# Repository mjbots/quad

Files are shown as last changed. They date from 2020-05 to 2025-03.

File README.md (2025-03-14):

mjbots quad
===========

Source and design files for the mjbots quad series of robots, their
controlling interfaces, and utilities for developing and operating
them.

* GitHub https://github.com/mjbots/mjmech
* Most files are free hardware and software: Apache 2.0 License
* Overall F360 assembly: https://a360.co/4bPBs6g

Directory structure
-------------------

* **base/** - C++ source files common to many applications.
* **ffmpeg/** - C++ ffmpeg wrappers.
* **gl/** - C++ GL wrappers.
* **mech/** - C++ source files specific to walking robots.
* **simulator/** - C++ source files for a quadruped simulator.
* **utils/** - Utilities for development and data analysis.
* **configs/** - Configuration files for different robots and applications.
* **hw/** - Hardware design files along with firmware.
* **docs/** - Documentation.

First Time Setup
----------------

The following should work on Ubuntu 20.04 or 22.04.

```
./install-packages
```

For Ubuntu 24.04, you will also need to manually download and install an appropriate libtinfo5 package from 22.04.  https://packages.ubuntu.com/jammy/amd64/libtinfo5/download

Building for host
-----------------

```
tools/bazel test //...
```

Running simulation
------------------

```
./bazel-bin/simulator/simulator -c configs/quadruped.ini
```

Then point your web browser to `http://localhost:4778`

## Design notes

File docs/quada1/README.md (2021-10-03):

# Getting started with the quad A1 #

## Safety ##

The mjbots quad A1 is a high performance robot capable of very fast
and powerful motions.  It is not recommended for use in the vicinity
of untrained personnel and especially not children or others who do
not appreciate what it is capable of.

Minimize physical handling of the robot while the power switch is on,
as malfunctions may cause legs to to move rapidly, creating pinch
hazards.

## Turn on ##

1. Ensure the switch is in the "off" position.  When off, the LED side of the switch is *not* depressed.

2. Insert a 4Ah ONE+ battery.  It may be necessary to apply a moderate tap with your fist in order to get both retaining clips to latch.

3. Flip the quad A1 over to be right side up and extend legs to be maximally stretched out, flat against the ground.  This is the "turn-on" position.
  * NOTE: The software is able to detect *some but not all* invalid
    turn-on positions.

4. Activate the power switch.  This means pressing the side with the LED down.

5. After ~30s, the robot's wifi access point will become available.  Connect to it.

6. Using Chrome, the only currently supported browser, navigate to http://192.168.16.47:4778

## Joystick ##

The web control application supports a connected gamepad, which is the
simplest means of controlling the robot.  The "Y/4" button on the
gamepad enables mode select, while the d-pad up and down allow you to
cycle between modes.  Once you pick a mode that is not "Stop", the
quad A1 will stand up.

While moving, the left analog stick controls translation, while the
left and right motion of the right analog stick controls yaw.

When stopped, the left trigger can be pulled to enable "emote mode".
In that mode, the analog sticks control the attitude of the body.

## Keyboard ##

It is also possible to operate the robot with a mouse and keyboard.
The mouse can be used to click and select a mode.  WASDQE keys can be
used to pilot the quad A1 as per the on-screen display.

# Maintenance #

## Belt tension ##

The leg belts need to be kept appropriately tensioned to minimize the
possibility of belt skipping, while not overly stressing the 3d
printed upper leg structure.  The M3 adjustment bolt in each leg can
be used to adjust that tension.  As the belts stretch with age, it
will likely be necessary to use a longer bolt than the M3x12 initially
installed.  M3x14 is the longest suitable bolt.

## Rezeroing leg ##

If the leg is disassembled or re-assembled, or the belt skips, then that leg will need to be re-zeroed.  This can be accomplished as follows:

1. Lay the quad A1 upside down on a flat surface.
2. Install the leg zeroing fixtures on the leg in question.  The lower
   leg qdd100 rests on the curved part of the large fixture, and the
   upper part restrains the upper leg.
3. The smaller fixture registers the upper and lower leg together.
   Slide it down as far as possible, then attempt to get the lower leg
   as centered as possible in any remaining play.
4. Connect to the robot and stop the existing software:

```
ssh -i mjmech/utils/ssh/mjbots.ssh pi@192.168.16.47
sudo screen -r
<CTRL-c>
```

5. Determine the leg number of the leg to be rezeroed.  When looking
   from the top, the legs are numbered as follows.  The "front" side
   is the one with the power switch. (note the robot is upside down
   now, so this will be mirrored):

```
   1      2

     FRONT

     BACK

   3      4
```

6. Rezero the leg, using the leg number from above.

```
./zero_leg.py -l 1
```

This will report the current position of each three leg servos.  Press
<enter> when the leg is in position to zero that leg.

7. If more legs need to be rezeroed, the fixture can be moved between
   legs and the step 6 command run more as necessary.

8. Shutdown the computer, wait 15s, then turn off the power switch.

```
shutdown -h now
```

9. At this point the quad A1 can be set in the "turn-on" position and
   started up as normal.

## Change ssh key ##

The quad A1 is initially provisioned with an ssh key that is common to
all machines.  This is not normally a problem, as the SSID is unique
and the password is secret.  If you wish to expose the quad A1 to a
wider network, first contact info@mjbots.com to discuss your risk
profile.  Second, you may wish to change the default ssh access key.

First, use `ssh-copy-id` to install a new key on the quad A1:

```
ssh-copy-id -o "-i utils/ssh/default.ssh" pi@192.168.16.47
```

Then, ssh in, and remove the old key.

```
ssh pi@192.168.16.47
vi .ssh/authorized_keys  # remove the info@mjbots.com line
```

## Upgrading software ##

1. Compile:

```
tools/bazel build --config pi -c opt //mech:quad_deploy.tar
```

2. Copy it to the robot:

```
rsync -Pv -e "ssh -i utils/ssh/default.ssh"  \
  bazel-out/armeabihf-opt/bin/mech/quad_deploy.tar pi@192.168.16.47:
```

3. Perform the upgrade and restart the software.

NOTE: If any configurations have been modified, you will want to
manually capture those now, as this process will reset all
configuration to factory default.

```
ssh -i utils/ssh/default.ssh pi@192.168.16.47
sudo screen -r
<CTRL-c>
cd /home/pi
sudo -u pi tar xvf quad_deploy.tar
sync
cd mech
./start-robot.sh
<CTRL-a d>
```

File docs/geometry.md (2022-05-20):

# mjmech geometry #

## Unit naming conventions ##

Quantities expressed in a certain unit should have that unit included
as a suffix that variable name.

## Frame naming conventions ##

Quantities which are expressed relative to some frame or frames have those frames suffixed on the variable name using the simbody conventions :https://simtk.org/docman/view.php/47/231/SimbodyTheoryManual.pdf

As there, common frames may be abbreviated with a single uppercase
letter.

## Frame conventions ##

Coordinate systems are right handed, if there is a human associated
direction, they should be interpreted as:

* x is positive forward
* y is positive right
* z is positive down

## Common frames ##

Leg Frame (G): The leg frame is located at the center of the shoulder
joint, with +x facing forward, +y facing right, and +z facing down.
In this case, "forward" is oriented away from the center of the robot
in the longitudinal direction, and "right" is measured relative to
that.

Body Frame (B): This frame is oriented at the center of the quadruped
body and fixed to the chassis.

CoM Frame (M): This frame is fixed to the chassis at the center of
mass as measured with the legs in idle position.  It is oriented to be
level with the ground, so +Z is always down w.r.t. gravity.  The frame
has a yaw such that +X is pointed to same heading as Body +X.

Attitude Frame (A): This frame is fixed to the chassis center of mass.
+Z is down w.r.t. gravity.  The rotation of +X/+Y is arbitrary at
power up, and follows the rotation of the B/L transform.

Robot Frame (R): This frame is offset from the Body Frame (B) and
referenced in the same manner, but may be offset or rotated to apply
cosmetic kinematic changes.

Terrain Frame (T): This frame is located at the center of mass,
projected along the body Z direction at the ground location.  It is
oriented parallel to the local ground terrain and rotated to be
consistent with the A frame.

Local Frame (L): This frame is oriented such that down is parallel to
gravity.  Other degrees of freedom are initialized with the quadrupeds
body center at turn on, and have no absolute correlation with the
outside world.

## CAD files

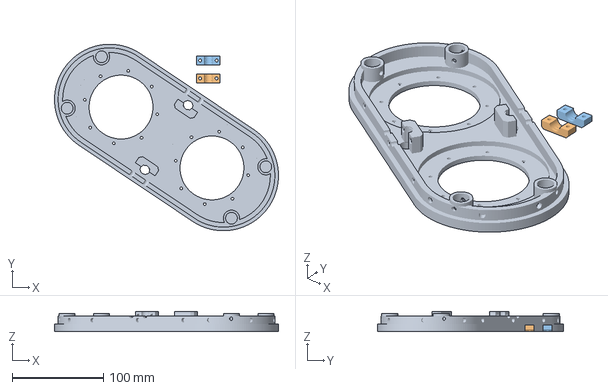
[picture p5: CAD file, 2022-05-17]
hw/chassis_a2/front_back_plate.3mf
245.6 x 204.4 x 22.0 mm
front_back_plate.stl
conduit_clamp.stl

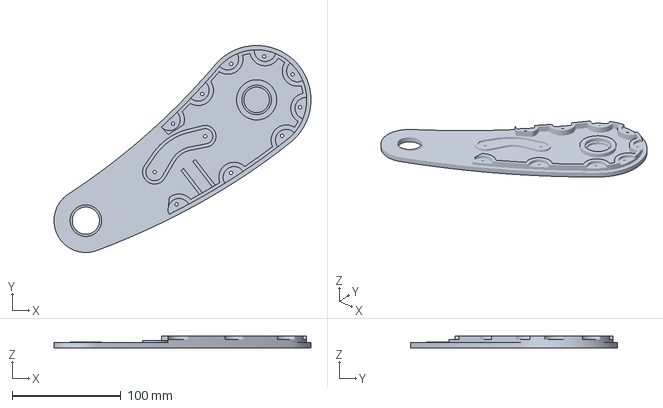
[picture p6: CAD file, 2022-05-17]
hw/leg_a2/upper_leg_right_top.3mf
236.4 x 190.4 x 11.0 mm

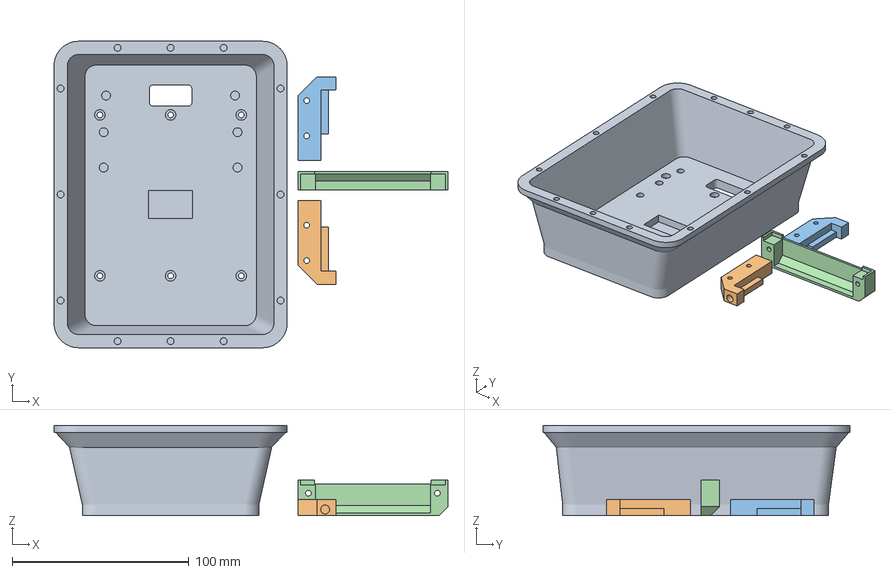
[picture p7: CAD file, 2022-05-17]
hw/chassis_a2/battery_tray.3mf
223.0 x 173.5 x 51.0 mm
battery_tray.stl
battery_rail_left.stl
battery_rail_right.stl
pcb_cover.stl

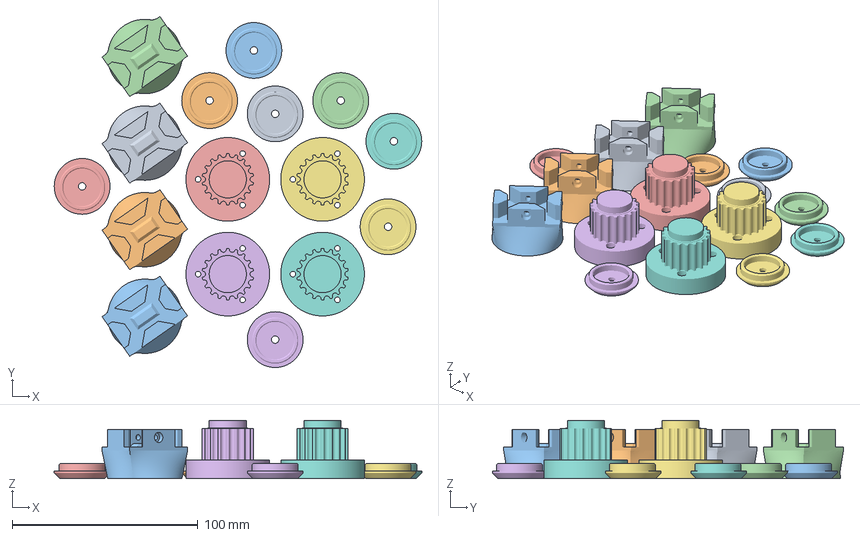
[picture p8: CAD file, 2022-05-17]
hw/leg_a2/4x_foot_axle_cap_pulley.3mf
197.7 x 188.9 x 31.3 mm
axle_cap.stl
foot.stl
upper_pulley.stl

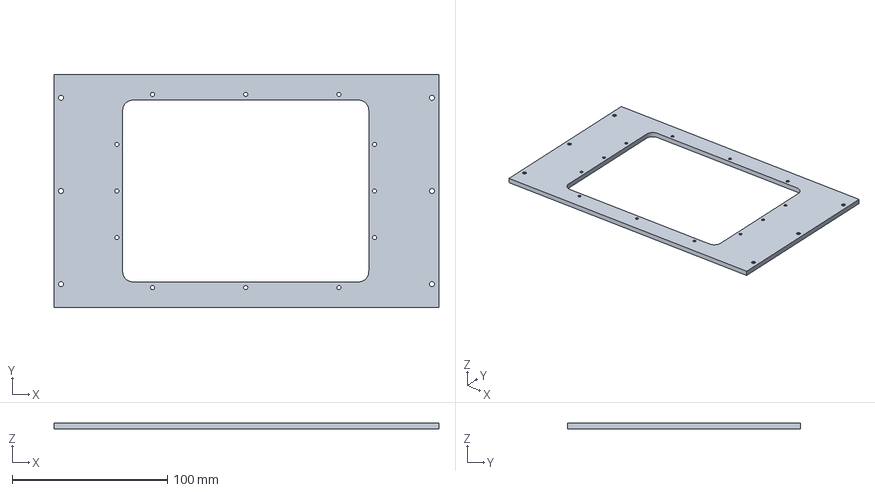
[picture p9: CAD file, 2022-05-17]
hw/chassis_a2/top.3mf
248.0 x 150.0 x 4.00 mm

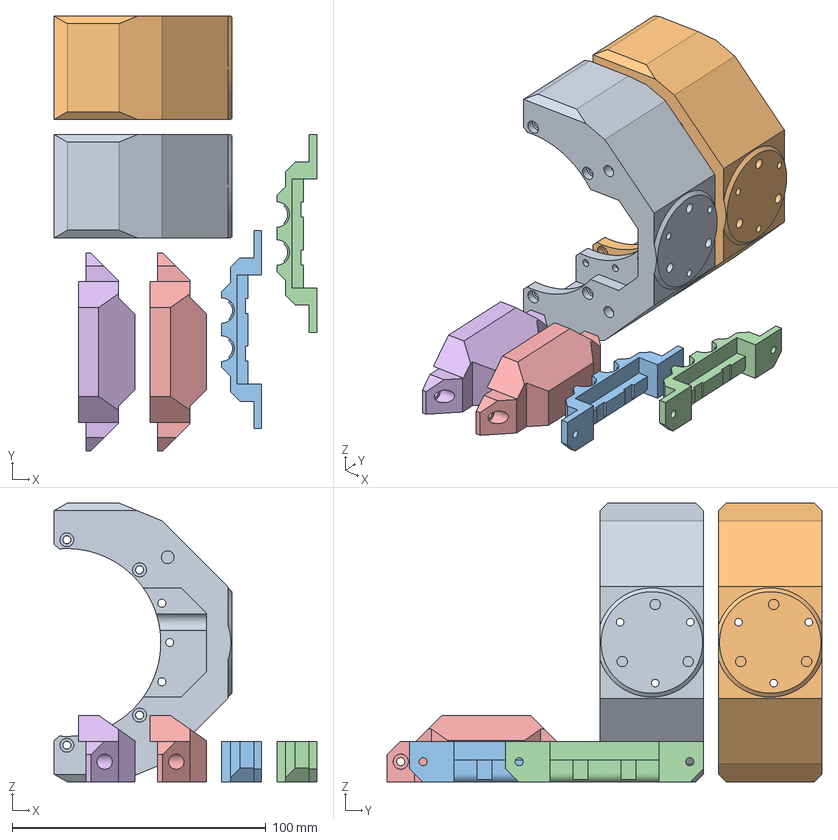
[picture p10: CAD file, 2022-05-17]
hw/leg_a2/2x_shoulder.3mf
103.5 x 171.4 x 110.0 mm
beta2_shoulder.stl
shoulder_clamp_bottom.stl
shoulder_clamp_top.stl

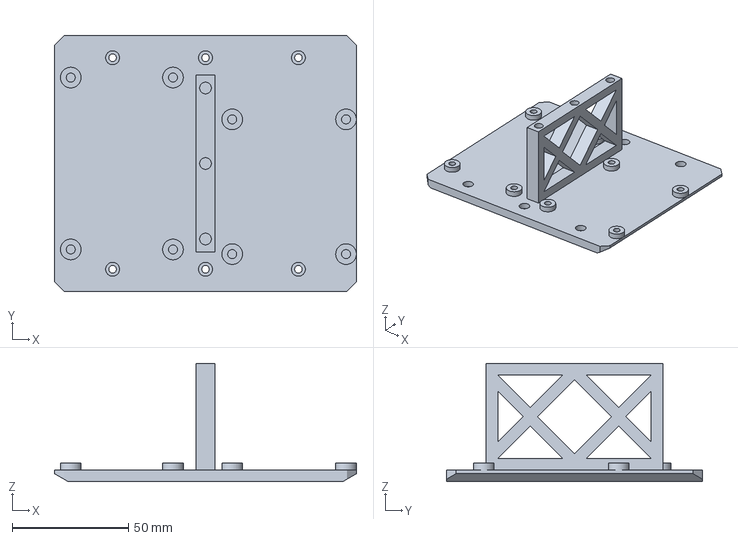
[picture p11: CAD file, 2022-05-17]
hw/chassis_a2/computer_tray.3mf
130.0 x 110.0 x 51.0 mm

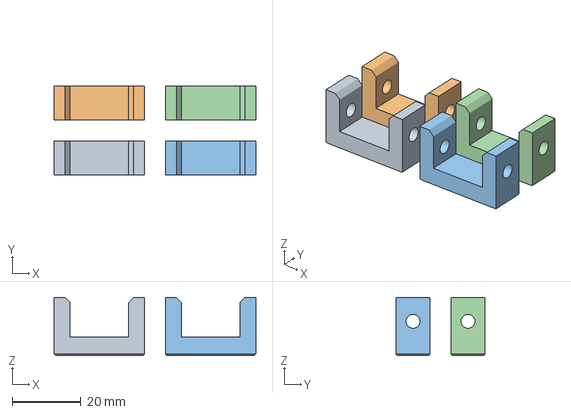
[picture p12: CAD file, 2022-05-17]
hw/leg_a2/4x_tensioners.3mf
58.8 x 26.0 x 17.0 mm

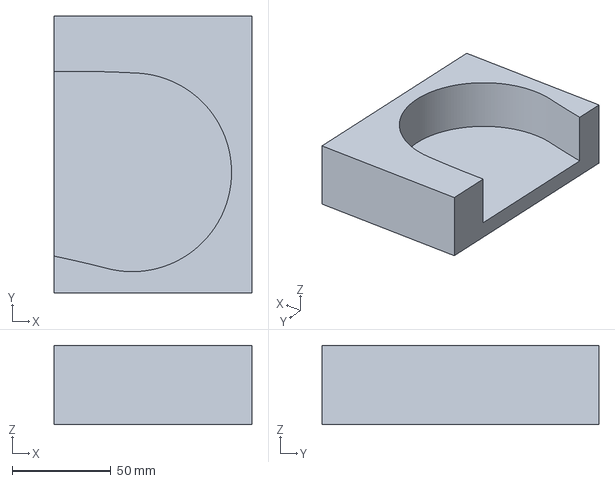
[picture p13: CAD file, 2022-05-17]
hw/chassis_a2/shoulder_zero_left.3mf
100.0 x 140.0 x 40.0 mm

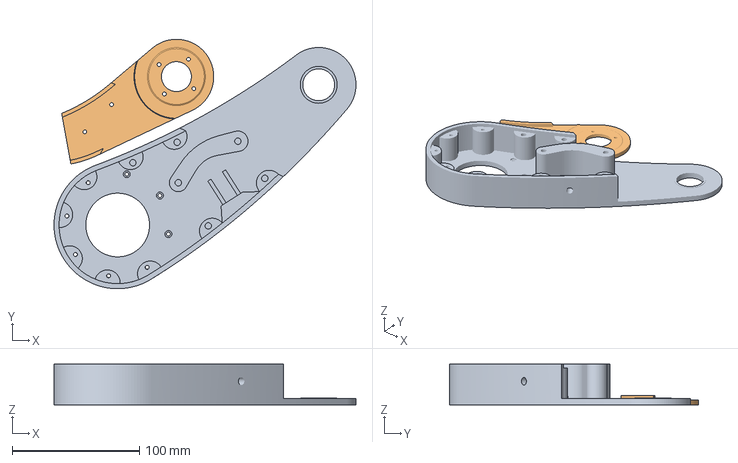
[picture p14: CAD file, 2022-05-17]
hw/leg_a2/upper_leg_right_base_lower_leg_top.3mf
237.1 x 195.8 x 32.0 mm
upper_leg_right_base.stl
lower_leg_top.stl

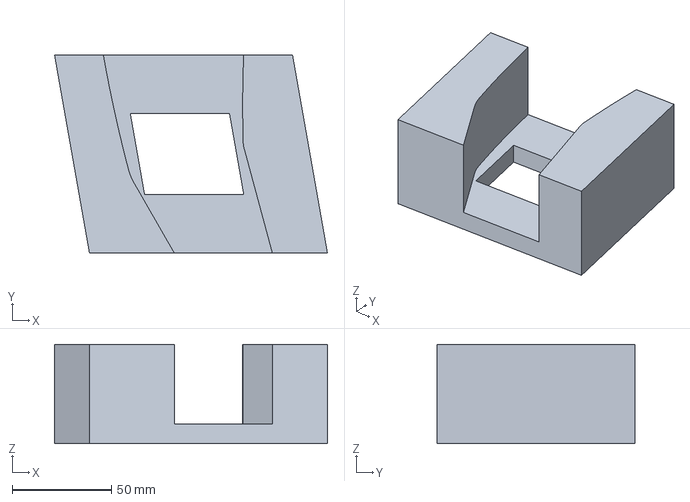
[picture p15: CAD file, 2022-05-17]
hw/chassis_a2/knee_zero.3mf
137.6 x 100.0 x 50.0 mm

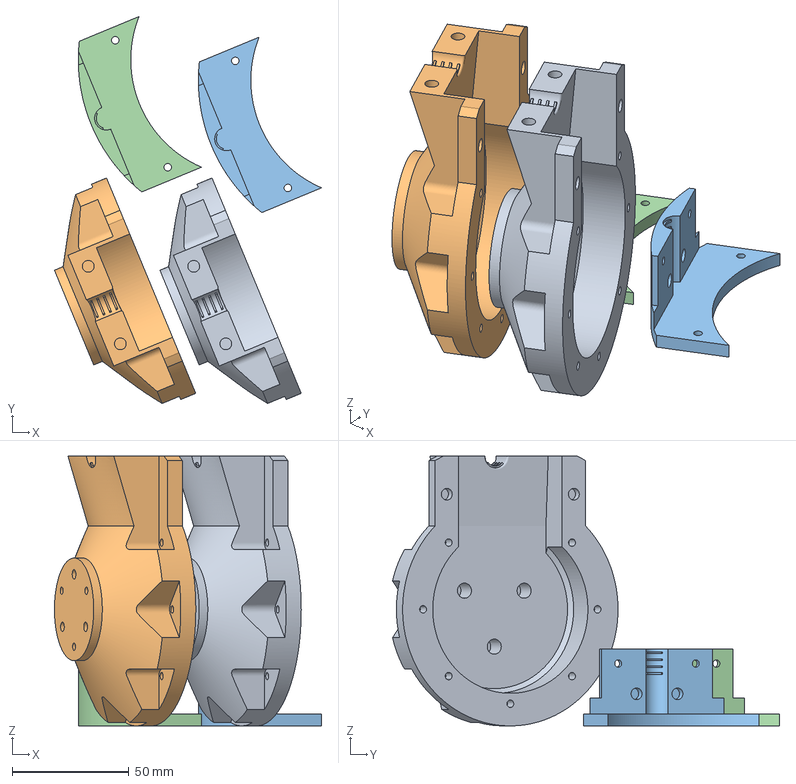
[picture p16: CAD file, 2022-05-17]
hw/leg_a2/2x_upper_motor.3mf
114.6 x 166.0 x 115.7 mm
upper_motor_joint.stl
upper_motor_clamp.stl

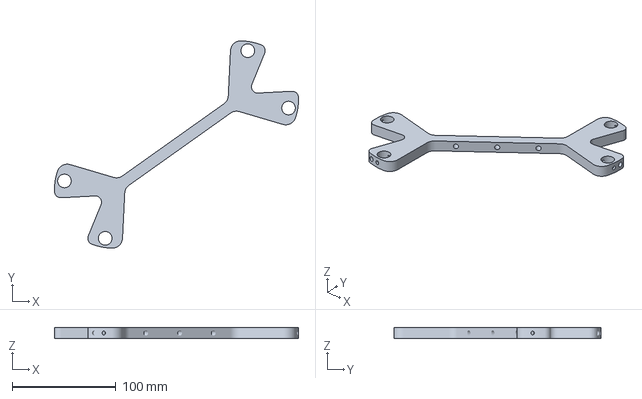
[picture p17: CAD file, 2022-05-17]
hw/chassis_a2/rail_carrier.3mf
235.3 x 199.9 x 11.1 mm

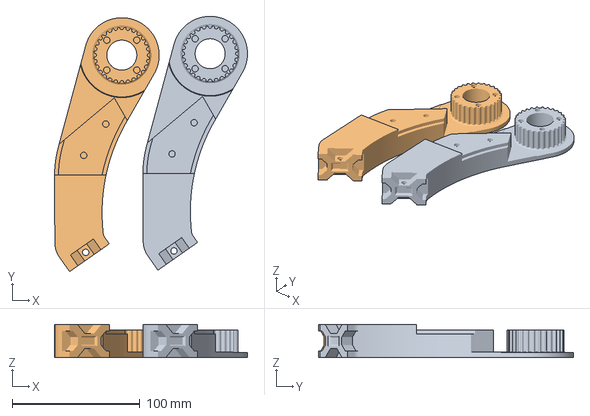
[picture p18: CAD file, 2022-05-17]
hw/leg_a2/2x_lower_leg_base.3mf
151.2 x 200.0 x 26.0 mm

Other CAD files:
hw/chassis_a2/side_wall.3mf
hw/leg_a2/upper_leg_base_lower_leg_top.3mf
hw/chassis_a2/bottom.3mf
hw/leg_a2/upper_leg_top.3mf
docs/diagrams/1d_swing.blend
docs/diagrams/support_line.blend
hw/chassis/3dprint/20200303-battery_stud.3mf
hw/chassis/3dprint/20200415-stiffener_left.3mf
hw/chassis/3dprint/20200415-stiffener_right.3mf
hw/chassis/3dprint/20200415-top.3mf
hw/chassis/3dprint/20200502-aligners.3mf
hw/chassis/3dprint/20200504-front_plate.3mf
hw/chassis/3dprint/20200506-bottom.3mf
hw/chassis/3dprint/20200506-internal_cover.3mf
hw/chassis/3dprint/20200708-shore_plug.3mf
hw/chassis/3dprint/20201223-sides.3mf
hw/chassis/3dprint/20231218-front_plate-0_6mm.3mf
hw/chassis/3dprint/20231218-sides-0_6mm.3mf
hw/chassis/3dprint/20231219-battery_stud-0_6.3mf
hw/chassis/3dprint/20231219-bottom-0_6mm.3mf
hw/chassis/3dprint/20231219-top-0_6mm.3mf
hw/chassis/3dprint/20231220-internal_cover-0_6mm.3mf
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

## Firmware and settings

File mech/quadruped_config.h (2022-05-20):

// Copyright 2019-2020 Josh Pieper, jjp@pobox.com.
//
// Licensed under the Apache License, Version 2.0 (the "License");
// you may not use this file except in compliance with the License.
// You may obtain a copy of the License at
//
//     http://www.apache.org/licenses/LICENSE-2.0
//
// Unless required by applicable law or agreed to in writing, software
// distributed under the License is distributed on an "AS IS" BASIS,
// WITHOUT WARRANTIES OR CONDITIONS OF ANY KIND, either express or implied.
// See the License for the specific language governing permissions and
// limitations under the License.

#pragma once

#include <vector>

#include "mjlib/base/visitor.h"

#include "base/point3d.h"
#include "base/sophus.h"
#include "mech/mammal_ik.h"

namespace mjmech {
namespace mech {

// This represents the JSON used to configure the geometry of the
// robot.
struct QuadrupedConfig {
  double period_s = 0.0025;
  double min_voltage = 16.0;

  struct Joint {
    int id = 0;
    double sign = 1.0;
    double rezero_pos_deg = 0.0;

    template <typename Archive>
    void Serialize(Archive* a) {
      a->Visit(MJ_NVP(id));
      a->Visit(MJ_NVP(sign));
      a->Visit(MJ_NVP(rezero_pos_deg));
    }
  };

  std::vector<Joint> joints;

  // The maximum error is about +-30 deg, so this will at least catch
  // some fraction of failures to position properly at startup.
  double rezero_threshold_deg = 15.0;

  struct Leg {
    int leg = 0;
    Sophus::SE3d pose_BG;
    MammalIk::Config ik;

    template <typename Archive>
    void Serialize(Archive* a) {
      a->Visit(MJ_NVP(leg));
      a->Visit(MJ_NVP(pose_BG));
      a->Visit(MJ_NVP(ik));
    }
  };

  std::vector<Leg> legs;

  struct Bounds {
    double min_z_B = 0.0;
    double max_z_B = 0.30;
    double max_acceleration = 100;

    template <typename Archive>
    void Serialize(Archive* a) {
      a->Visit(MJ_NVP(min_z_B));
      a->Visit(MJ_NVP(max_z_B));
      a->Visit(MJ_NVP(max_acceleration));
    }
  };

  Bounds bounds;

  double mass_kg = 10.0;
  double leg_mass_kg = 0.5;
  base::Point3D center_of_mass_B;

  struct StandUp {
    // This pose is referenced to the leg in the front right and the
    // x/y positions should all be positive.  All other positions will
    // be symmetric about the x/y axes.
    base::Point3D pose_R = {0.151, 0.240, 0.049};
    double velocity_dps = 60.0;
    double velocity = 0.150;
    double shoulder_clearance_deg = 52.0;
    double max_preposition_torque_Nm = 3.0;
    double preposition_kp_scale = 5.0;
    double timeout_s = 10.0;
    double tolerance_deg = 1.0;
    double tolerance_m = 0.001;
    double acceleration = 2.000;

    template <typename Archive>
    void Serialize(Archive* a) {
      a->Visit(MJ_NVP(pose_R));
      a->Visit(MJ_NVP(velocity_dps));
      a->Visit(MJ_NVP(velocity));
      a->Visit(MJ_NVP(shoulder_clearance_deg));
      a->Visit(MJ_NVP(max_preposition_torque_Nm));
      a->Visit(MJ_NVP(preposition_kp_scale));
      a->Visit(MJ_NVP(timeout_s));
      a->Visit(MJ_NVP(tolerance_deg));
      a->Visit(MJ_NVP(tolerance_m));
      a->Visit(MJ_NVP(acceleration));
    }
  };

  StandUp stand_up;

  struct Rest {
    double velocity = 0.100;

    template <typename Archive>
    void Serialize(Archive* a) {
      a->Visit(MJ_NVP(velocity));
    }
  };

  Rest rest;

  double stand_height = 0.210;

  double idle_x = 0.190;
  double idle_y = 0.140;

  base::Point3D default_kp_N_m = {1000.0, 1000.0, 200.0};
  base::Point3D default_kd_N_m_s = {20.0, 20.0, 20.0};

  double rb_filter_constant_Hz = 2.0;
  double lr_acceleration = 2.000;
  double lr_alpha_rad_s2 = 1.0;
  double terrain_filter_s = 0.5;
  double voltage_filter_s = 1.0;

  double zero_velocity_kd_scale = 1.5;

  struct Jump {
    double lower_velocity = 0.100;
    double retract_velocity = 1.000;
    double retract_acceleration = 100.000;
    double land_threshold = 0.015;
    double kp_scale = 10.0;
    double kd_scale = 1.0;
    double land_kp = 1.0;
    double land_kd = 0.1;
    double lower_height = 0.100;
    double upper_height = 0.220;
    double retract_height = 0.190;
    double landing_force_scale = 1.0;
    double land_gain_increase = 100.0;
    double min_acceleration = 0.500;
    double land_velocity = 0.01;

    template <typename Archive>
    void Serialize(Archive* a) {
      a->Visit(MJ_NVP(lower_velocity));
      a->Visit(MJ_NVP(retract_velocity));
      a->Visit(MJ_NVP(retract_acceleration));
      a->Visit(MJ_NVP(land_threshold));
      a->Visit(MJ_NVP(kp_scale));
      a->Visit(MJ_NVP(kd_scale));
      a->Visit(MJ_NVP(land_kp));
      a->Visit(MJ_NVP(land_kd));
      a->Visit(MJ_NVP(lower_height));
      a->Visit(MJ_NVP(upper_height));
      a->Visit(MJ_NVP(retract_height));
      a->Visit(MJ_NVP(landing_force_scale));
      a->Visit(MJ_NVP(land_gain_increase));
      a->Visit(MJ_NVP(min_acceleration));
      a->Visit(MJ_NVP(land_velocity));
    }
  };

  Jump jump;

  struct Walk {
    double lift_height = 0.025;
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

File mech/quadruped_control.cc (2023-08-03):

// Copyright 2019-2020 Josh Pieper, jjp@pobox.com.
//
// Licensed under the Apache License, Version 2.0 (the "License");
// you may not use this file except in compliance with the License.
// You may obtain a copy of the License at
//
//     http://www.apache.org/licenses/LICENSE-2.0
//
// Unless required by applicable law or agreed to in writing, software
// distributed under the License is distributed on an "AS IS" BASIS,
// WITHOUT WARRANTIES OR CONDITIONS OF ANY KIND, either express or implied.
// See the License for the specific language governing permissions and
// limitations under the License.

#include "mech/quadruped_control.h"

#include <fstream>

#include <boost/algorithm/string.hpp>
#include <boost/asio/post.hpp>

#include <fmt/format.h>

#include "mjlib/base/clipp_archive.h"
#include "mjlib/base/json5_read_archive.h"

#include "mjlib/io/now.h"
#include "mjlib/io/repeating_timer.h"

#include "base/common.h"
#include "base/fit_plane.h"
#include "base/interpolate.h"
#include "base/logging.h"
#include "base/sophus.h"
#include "base/telemetry_registry.h"
#include "base/timestamped_log.h"

#include "mech/attitude_data.h"
#include "mech/mammal_ik.h"
#include "mech/moteus.h"
#include "mech/quadruped_config.h"
#include "mech/quadruped_context.h"
#include "mech/quadruped_trot.h"
#include "mech/quadruped_util.h"
#include "mech/swing_trajectory.h"
#include "mech/trajectory.h"

namespace pl = std::placeholders;

namespace mjmech {
namespace mech {

namespace {
constexpr int kNumServos = 12;

using QC = QuadrupedCommand;
using QM = QC::Mode;

template <typename Iter, typename Functor>
auto Average(Iter begin, Iter end, Functor f) -> decltype(f(*begin)) {
  using T = decltype(f(*begin));

  T sum = {};
  double count = {};
  for (Iter it = begin; it != end; ++it) {
    count++;
    sum += f(*it);
  }
  return (1.0 / count) * sum;
}

template <typename Iter, typename Functor>
auto Max(Iter begin, Iter end, Functor f) -> decltype(f(*begin)) {
  using T = decltype(f(*begin));

  MJ_ASSERT(begin != end);

  T current = f(*begin);
  Iter it = begin;
  ++it;
  for (; it != end; ++it) {
    const auto value = f(*it);
    if (value > current) { current = value; }
  }
  return current;
}

template <typename Iter, typename Functor>
auto Min(Iter begin, Iter end, Functor f) -> decltype(f(*begin)) {
  using T = decltype(f(*begin));

  MJ_ASSERT(begin != end);

  T current = f(*begin);
  Iter it = begin;
  ++it;
  for (; it != end; ++it) {
    const auto value = f(*it);
    if (value < current) { current = value; }
  }
  return current;
}

struct ReportedServoConfig {
  boost::posix_time::ptime timestamp;

  struct Servo {
    int id = 0;
    int rezero_state = 0;
    int register_map_version = -1;
    std::array<uint8_t, 12> serial_number = {};

    template <typename Archive>
    void Serialize(Archive* a) {
      a->Visit(MJ_NVP(id));
      a->Visit(MJ_NVP(rezero_state));
      a->Visit(MJ_NVP(register_map_version));
      a->Visit(MJ_NVP(serial_number));
    }
  };

  std::vector<Servo> servos;

  template <typename Archive>
  void Serialize(Archive* a) {
    a->Visit(MJ_NVP(timestamp));
    a->Visit(MJ_NVP(servos));
  }
};

using Config = QuadrupedConfig;

struct CommandLog {
  boost::posix_time::ptime timestamp;

  const QC* command = &ignored_command;

  template <typename Archive>
  void Serialize(Archive* a) {
    a->Visit(MJ_NVP(timestamp));
    const_cast<QC*>(command)->Serialize(a);
  }

  static QC ignored_command;
};

QC CommandLog::ignored_command;
}

class QuadrupedControl::Impl {
 public:
  Impl(base::Context& context,
       Pi3hatGetter pi3hat_getter)
      : executor_(context.executor),
        telemetry_log_(context.telemetry_log.get()),
        timer_(executor_),
        pi3hat_getter_(pi3hat_getter) {
    context.telemetry_registry->Register("qc_status", &status_signal_);
    context.telemetry_registry->Register("qc_command", &command_signal_);
    context.telemetry_registry->Register("qc_control", &control_signal_);
    context.telemetry_registry->Register("imu", &imu_signal_);
    context.telemetry_registry->Register("servo_config", &servo_config_signal_);
  }

  void AsyncStart(mjlib::io::ErrorCallback callback) {
    pi3hat_ = pi3hat_getter_();

    BOOST_ASSERT(!!pi3hat_);

    // Load our configuration.
    std::vector<std::string> configs;
    boost::split(configs, parameters_.config, boost::is_any_of(" "));
    for (const auto& config : configs) {
      std::ifstream inf(config);
      mjlib::base::system_error::throw_if(
          !inf.is_open(),
          fmt::format("could not open config file '{}'", parameters_.config));

      mjlib::base::Json5ReadArchive(inf).Accept(&config_);
    }

    if (config_.legs.size() != 4 ||
        config_.joints.size() != kNumServos) {
      mjlib::base::Fail(
          fmt::format(
              "Incorrect number of legs/joints configured: {}/{} != 4/12",
              config_.legs.size(), config_.joints.size()));
    }

    context_.emplace(config_, &current_command_, &status_.state);

    PopulateStatusRequest();

    period_s_ = config_.period_s;
    timer_.start(mjlib::base::ConvertSecondsToDuration(period_s_),
                 std::bind(&Impl::HandleTimer, this, pl::_1));

    boost::asio::post(
        executor_,
        std::bind(std::move(callback), mjlib::base::error_code()));
  }

  void Command(const QC& command) {
    const auto now = Now();
    const bool higher_priority = command.priority >= current_command_.priority;
    const bool stale =
        !current_command_timestamp_.is_not_a_date_time() &&
        (mjlib::base::ConvertDurationToSeconds(
            now - current_command_timestamp_) > parameters_.command_timeout_s);
    if (!higher_priority && !stale) {
      return;
    }

    CommandLog command_log;
    command_log.timestamp = now;
    command_log.command = &command;

    current_command_ = command;
    current_command_timestamp_ = now;

    // Update our logging status.
    if (command.log != QuadrupedCommand::Log::kUnset) {
      if (command.log == QuadrupedCommand::Log::kEnable &&
          !telemetry_log_->IsOpen()) {
        base::OpenMaybeTimestampedLog(
            telemetry_log_,
            parameters_.log_filename_base,
            base::kTimestamped);
      } else if (command.log == QuadrupedCommand::Log::kDisable &&
                 telemetry_log_->IsOpen()) {
        telemetry_log_->Close();
      }
    }

    command_signal_(&command_log);
  }

  void PopulateStatusRequest() {
    status_request_ = {};
    for (const auto& joint : config_.joints) {
      status_request_.push_back({});
      auto& current = status_request_.back();
      current.id = joint.id;

      // Read mode, position, velocity, and torque.
      current.request.ReadMultiple(moteus::Register::kMode, 4, 1);
      current.request.ReadMultiple(moteus::Register::kVoltage, 3, 0);

      if (parameters_.servo_debug) {
        current.request.ReadMultiple(moteus::Register::kPositionKp, 5, 1);
      }
    }
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

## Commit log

2014-02-01 Several tweaks: * Update .gitignore. * Make sign be consistent on left vs. right joints. * Update gains to be stiffer.
2014-02-15 Update model to be closer to reality. This has approximately correct masses, (although more weight in the legs than is realistic at the moment).
2014-02-21 Beginnings of GUI to command servos. Doesn't work yet.
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2015-09-12 File some more work into different directories to clean up the root.
    [real.cfg, real_dynamic_high.cfg, real_dynamic_low.cfg]
2015-09-12 Preliminary re-organization of current source files into a top-level hierarchy. Currently doesn't build or do anything useful.
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2015-09-25 Update configs to be more appropriate for the current mammal robot.
    [real.cfg]
2015-09-25 herkulex: When reporting an error caused by reading a ram address, always include the servo number which caused the error.
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2015-10-24 ServoMonitor: Refactor the underlying layers so that ServoMonitor can get at the HerkuleX status field. Use that information to try and log and reset errors that it observes in the servos during the 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
2015-11-04 ServoMonitor: Try to make clearing errors work correctly.
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2015-11-13 Switch to using a concrete stream factory everywhere, so that all classes which need stream communication don't need to be themselves templated.
    This doesn't help compile time or compiler memory usage nearly as much
    as I had hoped, but it does make things like the servo driver easier
    to write since many fewer "typename"s are required.
2015-11-18 Fix compilation error in imu driver. This may need to be protected by ifdef, but I am not sure what the porper ifdef is.
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2015-11-21 video sender: fix a race in thread initialization
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2015-12-17 link: wireless link setup scripts - Add 'info-networking.txt' which is a braindump for all network-related info - Convert setup_wifi_link script from sh to py, as it was getting too big - Add the sup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
2015-12-27 simulator: Checkpoint of simulator which kind of builds a mammal mech model. The joints aren't likely to be correct, and neither is the overall positioning.
    [simulator_window.cc]
2015-12-27 simulator: Make the model be roughly correctly linked. * The joints move in the correct axis. * The model is upright and above the ground. * You can use the keyboard to move all of the joints.
    [simulator_window.cc]
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2015-12-30 configs/real.cfg: Update with what the latest legtool emits.
    [real.cfg]
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2016-01-01 simulator: Make the robot be much closer to physically real: * Limited the maximum speed and force of each servo joint. * Use somewhat correct mass and moment of inertia * Start trying to model the f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
    [simulator_window.cc]
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2016-01-03 simulator: Tweak body COM and starting position so that the robot doesn't flip over on startup for default settings.
    [simulator_window.cc]
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2016-01-14 simulator: Attempt to fill in values for the IMU simulation. It seems likely I have some signs and rotations wrong, but this at least makes it through to the UKF on the mech and does not incredibly s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
2016-01-15 simulator: Get all rates and linear accelerations to be at least the correct sign for my sample experiments.
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2016-01-23 real.cfg: Switch the joint direction so that all joints have the knee pointing away from the body. This seems to work better with a fully weighed down robot.
    [real.cfg]
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2016-01-26 Update the real config to be something that works better with the current servo configuration.
    [real.cfg]
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2016-01-29 turret: Modify to be stateless and rely on the gimbal board to do rate based operation.
    Also, fix up HerkuleX so that writing values obeys bit_align, and use
    HerkuleXConstants::Register for all the definitions in turret.
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2016-02-01 ServoMonitor: Treat synchronization errors the same as timeouts, since the turret already does so too.
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2016-02-10 real.cfg: Update with slightly better config for real robot when loaded on carpet.
    [real.cfg]
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2016-02-10 Provide a new gimbal config with updated constants. Notably, this enables the boost converter, now that derating is supported.
    [gimbal_config.txt]
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2016-02-11 video: show h264 caps which we send over the wire; force the right caps on the appsink. This allows one to use non-h264 cameras over the network, and fixes sender-side video recording.
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2016-02-25 configs: Add a draft lizard config for SMMB.
    [lizard.cfg]
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2016-02-25 configs: Update lizard config to something which will work and tweak all gait update rates to be at 80Hz.
    [lizard.cfg]
2016-02-26 McastVideoLink: Fix a trivial bug that mis-calculated the total remaining bytes necessary for a given frame, resulting in assertions.
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2016-02-26 VideoControllerApp: Attempt to display the minimal telemetry as an OSD overlay, using the gstreamer textoverlay element. The simulator doesn't present useful information for anything we care about cu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
2016-02-29 configs: Add gimbal configuration for the gimbal currently on the lizard robot.
    [lizard_gimbal_config.txt]
2016-03-01 GstMainLoop: Fix thread safety issues that come up when destroying itself immediately after creating it.
2016-03-01 GstMainLoop: SignalReady was expected to be called from the gstreamer thread, and wasn't actually critical to the problems I was solving earlier. Put it back to being called from a gstreamer thread.
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2016-03-06 MechWarfare: Add a flag to Drive mode which temporarily prevents rotating the base to get into position. Make the controller set this flag when one of the shoulder buttons is pressed. This should all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
2016-03-07 Update gimbal configs with the gimbals currently on each robot.
    [gimbal_config.txt, lizard_gimbal_config.txt]
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2016-03-11 MechWarfareCommand: Make the "start" button toggle whether to stop sending messages. This can be used to reset the servos.
2016-03-30 mech_warfare_command: Get the correct start button for the logitech joystick and start paused by default.
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2016-12-03 [robogames2016] update robot config with the new servo calibration
    [real.cfg]
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2017-06-13 Provide a mechanism to write raw received frames to disk
    This can be helpful in analyzing the h264 bitstream or other protocol
    level failures.
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2019-04-26 Support tibia's that are commanded in a *non* relative way
    [real.cfg]
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2019-04-28 Fix all the signs for the moteus config
    [moteus_ik.cfg]
2019-04-29 Support getting in and out of walking semi-gracefully
    [moteus_ik.cfg]
2019-04-29 Tweak configs to give slightly more accurate IK
    [moteus_ik.cfg]
2019-05-02 Fix the IK to be correct!
    [moteus_ik.cfg]
2019-05-02 Make sitting and standing more reliable
    This does the stand and sit part in IK space, but not yet the
    prepositioning.
    During prepositioning, instead we now gradually ramp up the power of
    the tibias so as to avoid them getting stuck on the ground. Talk
    about breaking abstraction layers Batman!
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2019-05-03 When we see an error, cut power to everything
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2019-05-06 Support feed-forward torques
    This just compensates for the mass of the robot by assuming that much
    Z force is required at all times, distributed among all legs which are
    in contact with the ground. Assuming an appropriately set mass, this
    results in less sag during flight periods.
    [moteus.h]
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2019-05-06 Provide for a separate lift and lower percent
    [moteus_ik.cfg]
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2019-05-08 Correct some signs on torque calcuations
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2019-05-14 Stop commanding a speed during the sit and stand phase
    We are now interpolating IK, and commanding a speed just resulted in a
    steady state position error, making the legs slide around.
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2019-09-15 Stop using a hand-rolled Point3D and boost::property_tree
    Instead, Point3D is now just an alias to Eigen, and we directly use
    mjlib's JSON5 handlers for everything property_tree was used for.
    While we are at it, delete the python legtool bits. legtool is sadly
    defunct now, a new solution will be needed.
    [moteus_ik.cfg]
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2019-09-20 moteus_servo: Implement a configurable global maximum torque
    This can be used to test things that might otherwise result in crazy
    movements, without too much risk of destroying the machine.
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2019-09-20 Implement a more relaxed startup sequence that works from the ground
    "resting" legs are no longer needed. After standing, the machine
    takes a step to get into the normal walking position. Before sitting,
    it takes a step to get into the squatting position.
    [moteus_ik.cfg]
2019-09-21 Fix signs of all femurs and tibias
    [moteus_ik.cfg]
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2019-10-04 When a servo fault occurs, command the kPositionTimeout mode
    This should reduce the amount of damage that occurs during a fall, as
    at least some of the servos will cushion the fall.
    [moteus.h]
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2019-10-16 new-IK constify and fix frame name
2019-10-16 Beginnings of a new top level control scheme
    It runs on the rpi, but is likely broken in many ways
    [quada0.cfg]
2019-10-16 quadruped: Get signs and transforms working for quada0
    [quada0.cfg]
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2019-10-18 Get standing up to work
    Also, robustify things against missing replies
    [quadruped_control.cc]
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2019-10-21 Make the jump mode actually work
    * Fix an off by 10 unit error when calculating force from acceleration
    * When landing, start the z profile from the current position
    * When in flight, don't start landing if there is no force yet
    * When in flight, wait for some amount of time of valid criteria
    before switching to landing
    [quadruped_control.cc]
2019-10-21 Further improve jumps * A single jump now reverts to rest mode * You can command something other than jump and not read an unset optional
    [quadruped_control.cc]
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2019-10-29 Record missing replies in the binary log instead of text
    [quadruped_control.cc]
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2020-02-27 Fix enough rpi3 hat things so that at least 2 devices per bus works
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2020-03-06 Make it possible to, and then invert the front legs
    Now we don't look quite so silly walking around by default, although
    when the feet placement are symmetric, the range of motion is reduced.
    [quada1.cfg]
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2020-03-19 Fix two minor problems with jumping
    1. We were erroneously using the landing acceleration for the pushing
    phase as well
    2. The final cycle of landing was using an inappropriate extra Z force
    [quadruped_control.cc]
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2020-03-25 Populate simulation with something of roughly correct dimensions
    [quadruped_config.h, quadruped_control.cc, simulator_window.cc]
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2020-03-28 Update quaternion to use the conventions from geometry.md
    Delete anything that needed to be updated which isn't currently used.
    [lizard.cfg, moteus_ik.cfg, real.cfg]
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2020-04-02 Speed up the default rest, standup, and jump speeds
    [quada1.cfg]
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2020-04-07 Improve the jumping heuristics
    Now, we reliably switch to landing mode shortly after touching the
    ground, since we just look for displacement instead of velocity.
    Also, continually calculate a trajectory when landing so we
    semi-accurately approach the bottom of the jump. This still doesn't
    work all that well yet, so impose a minimum downward velocity also.
    [quada1.cfg]
2020-04-16 Update config and simulator to new leg geometry
    Not built on robot yet!
    [quada1.cfg]
2020-04-16 Implement a basic front push mode
    This is enough to get into a "belly" backflip, in sim... still need to
    implement the back pushing phase, and maybe back push some in the
    first pushing phase to keep the legs on the ground. I'm not sure how
    inaccurate the moment of inertias are in sim.
    [quada1.cfg]
2020-04-25 Add a snapshot of the gimbal config for moteus
    [moteus_gimbal_config.txt]
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2020-04-25 Remove an unused include and fix the fallout
    [quadruped_control.cc]
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2020-04-27 Actually report the timestamp again
    This was broken by f3f70ff5eb4d58b6fd048fdb99eb46a7c1a0c056
    [quadruped_control.cc]
2020-04-28 First backflip to make it kinda all the way around
    [quada1.cfg]
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2020-04-28 Get backflips to work with a 5% torque increase
    I haven't actually calibrated any of the physical parameters in the
    simulation, so has the potential to be more promising than it seems.
    [quada1.cfg]
2020-04-28 Tweak constants so to land the flip at 0.85 max torque
    [quada1.cfg]
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2020-05-03 Fix off by one error that allows maximum-size CAN frames to be sent
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2020-05-04 simulator: Add realistic tibia joint limits
    Tweak a1 config so that this works at least minimally
    [quada1.cfg]
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2020-05-07 Make balance use force control for stance legs
    [quada1.cfg]
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2020-05-09 tplot2: Fix seeking
    Turns out std::map::insert doesn't overwrite.
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2020-05-15 Make a "reset view" button
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2020-05-15 Render the ground and fix attitude transformation
    In the process, move the model transform back into C++ to make it
    easier to ensure the ground is rendered with a known transform in the
    "attitude enabled" case.
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2020-05-23 When jumping, don't go back to rest, since it prevents non-repeat operation
    [quadruped_control.cc]
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2020-05-23 A balance mode that works at least a little in sim
    [quada1.cfg]
2020-05-27 Correctly calculate velocities while moving
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2020-05-29 Select swing target using expected velocity rather than current
    [quada1.cfg]
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2020-06-06 Work towards making jump work in the new low-gain world
    It doesn't work great yet on the robot. I think we need feedforward
    accelerations to make tracking work better during retract.
    [quadruped_config.h, quadruped_control.cc]
2020-06-06 Explicitly command acceleration of each leg
    This removes some "extra_z" hacks, and makes it possible for the lower
    level controller to apply a feed forward term based on the joint
    acceleration. This doesn't end up working all that well, as the
    unloaded leg isn't that well approximated by a point mass, but it is
    more sound and reduces the number of special cases.
    Re-work the standup logic to use this framework, as well as give it
    acceleration limited tweens into the final position.
    [quada1.cfg]
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2020-06-12 Initial conversion to use the new pi3hat firmware and software library
    This still has some performance issues
    [quadruped_control.cc, simulator_window.cc]
2020-06-13 Many timing fixes for new pi3hat library
    [quadruped_control.cc, simulator_window.cc]
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2020-06-18 Report when we skip a cycle
    [quadruped_control.cc]
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2020-06-24 Switch everything from mm to m
    Delete a few more stale files rather than convert them
    [quada0.cfg, quada1.cfg]
2020-06-24 Use the correctly named "M" frame
2020-06-24 Directly log the MB frame and use that to simplify frame registration in tplot
    The MB frame currrently isn't configured with the correct offset (as
    that was the previous tplot2 behavior as well).
    [quadruped_control.cc]
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2020-06-26 Be smarter about picking swing legs after reversing
    Previously, we would just always pick the same foot. Now we look to
    see which one would result in moving over a balance point. (We'd do
    this every time, except we don't yet have a check on time to
    infeasibility).
2020-06-26 Optionally start the simulated yaw from a cmdline offset
    In real life the initial reported yaw is arbitrary. This can help
    discover problems where we depend on it being a certain way.
    [simulator_window.cc]
2020-06-26 Adjust CoM location based on an estimate of the current terrain
    This changes a number of things:
    First, the RB offset is no longer commandable across all gaits. There
    is instead a "rest" only option to add an additional offset to that
    command.
    Second, there is a new "T" frame, which is an estimate of the terrain
    under the robots feet. That is estimated recursively based on feet
    that are marked as being in stance and the current M frame with an
    exponential filter.
    Finally, all the gaits now apply a RB offset to get the CoM to be over
    the center of support based on the current terrain. This lets it walk
    over the simulated ramp of size up to 0.35, (and 0.4 backwards).
    [quada1.cfg]
2020-06-29 Be slightly smarter about foot lift selection
    Now we calculate a valid region, and force the feet to lift if it
    looks like a leg is going to reach the point where it would otherwise
    go invalid.
    [quada1.cfg]
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2020-07-09 Fault if the voltage gets too low
    [quadruped_config.h, quadruped_control.cc]
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2020-08-01 Fix sign conventions so that CoM renders correct in tplot2
    This changes the strategy for selecting the RB transform to one that
    is hopefully as sound, but also works when everything has the correct
    sign.
    [quadruped_control.cc]
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2020-08-04 Provide buttons to reset to known camera locations
    Also provide a non-functional switch between perspective and ortho modes
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2020-08-05 First pass at an improved trot gait
    There are still some outstanding usability issues, like making it
    easier to drive in low speed, and also the stability at high speed
    still isn't great.
    [quada1.cfg]
2020-08-07 Fix conflation of M frame
    We were in some places assuming the M frame was locked to the gyro
    heading, and other places assuming it was locked to the body heading.
    Make two separate frames with those two conventions and use them where
    appropriate.
    The net result was that the CoM was accounted for incorrectly, in a
    way that would vary depending upon which direction the robot was
    pointed!
    While we are at it, make tplot2 able to view from any of the relevant
    frames, and make it able to show commanded support regions, to make
    debugging these types of problems easier.
    [quadruped_control.cc]
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2020-08-24 Remove the old swing_time constant, replacing it with the new calculated version
    [quada1.cfg]
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2020-09-02 Build the simulator dynamically linked
    Statically linked binaries can cause problems with mesa drivers that
    also link to libstdc++.
2020-09-04 Calculate joint velocities using the current, not ideal positions
    We were already doing this for torque, and it makes sense to do it for
    velocities too. Near extremal positions, the velocities can change
    drastically, which can result in force application in significantly
    the wrong direction.
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2020-09-04 Add a double check to prevent negative servo gains
    [quadruped_control.cc]
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2020-09-04 Make the trot gait more robust
    This includes several changes to smooth out transitions in the trot
    gait, making it stable across a wider range of speeds and terrains:
    * When nearing the end of the flight phase, scale the kp and kd of
    the leg, gradually ramping them back up after the foot is in
    stance.
    * When first in stance, start with a stance value < 1.0 and gradually
    ramp it up. When other legs are already down, this makes the
    transition of force more gradual (but doesn't change anything if
    we're landing from a flight phase).
    * Use a heuristic to detect when a leg first makes contact with the
    ground. When it does, reset the control position to the actual
    positio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
    [quada1.cfg]
2020-09-09 Simplify the restorative velocity calculation by saving some state and no longer ramping it down
    [quadruped_config.h]
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2020-09-17 Add an option which can be used to fudge extra target time
    [quada1.cfg]
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2020-10-28 Make Saturate actually correct
    [moteus.h]
2020-10-28 Add support for "jumping" during the walking phase
    However, disable it in configuration because the current PD controller
    just isn't stable if there is a flight time of non-significant
    duration.
    Tweak the other constants for optimal performance. We now have decent
    results on flat ground across the full range from 0-2.5m/s and on
    rough terrain at slow speed, assuming the current gain on the qdd100s
    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
    [quada1.cfg]
2020-11-03 Make restoring values work more reliably
    Reading cookies currently parses the cookies as JSON. For select
    elements, that means that the values may no longer be an exact match.
    Thus, when restoring, we compare the saved value against each option
    parsed as JSON.
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2020-12-24 Add the actual chassis 3d prints
    Previously, this was just a duplicate of the leg
    [20200223-shoulder.3mf, 20200303-battery_stud.3mf, 20200415-stiffener_left.3mf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]
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2021-01-31 Another fix for python based moteus_tool
    [config_servos.py]
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2021-03-10 Fix typo in async_readline
    [zero_leg.py]
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2021-06-09 Update the default mounting angle to be correct
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2021-07-14 Actually report which servos might be at fault if some are missing
    [quadruped_control.cc]
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2022-05-17 Initial support for quad A2
    Walks very poorly, but it does walk!
    [quada2.cfg]
2022-05-20 Make terrain compensation more sound
    Now, we compensate assuming that the B frame is parallel to the T
    frame. That prevents a positive feedback loop from forming in the
    compensation.
    Also, fix the docs for the T frame.
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2023-07-17 Fix the simulated servo to use the new home state
    [simulator_window.cc]
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
